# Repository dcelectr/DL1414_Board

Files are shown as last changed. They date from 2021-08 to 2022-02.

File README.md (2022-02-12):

# DL1414_Board
Board design files for Litronix / Siemens / HP DL1414 16-Segment LED displays.
Each board can be stacked with another board and increase the number on total digits.

Arduino test code (scrolling text) for one module is in the [DL1414_74HC595](https://github.com/dcelectr/DL1414_Board/blob/main/DL1414_74HC595/DL1414_74HC595.ino) folder.

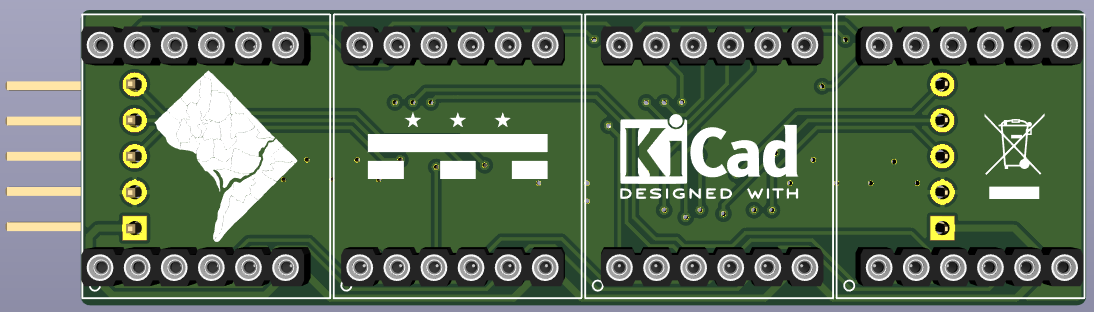
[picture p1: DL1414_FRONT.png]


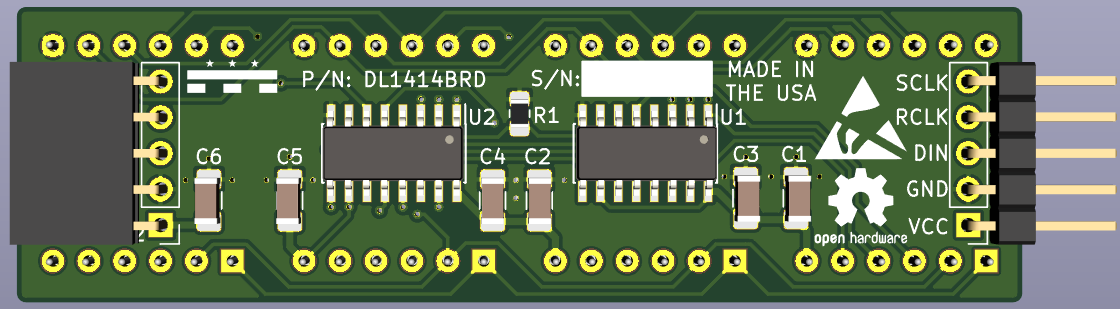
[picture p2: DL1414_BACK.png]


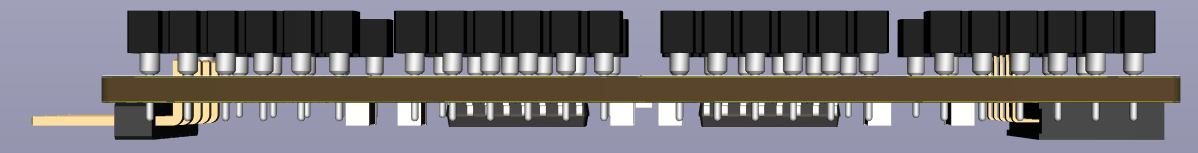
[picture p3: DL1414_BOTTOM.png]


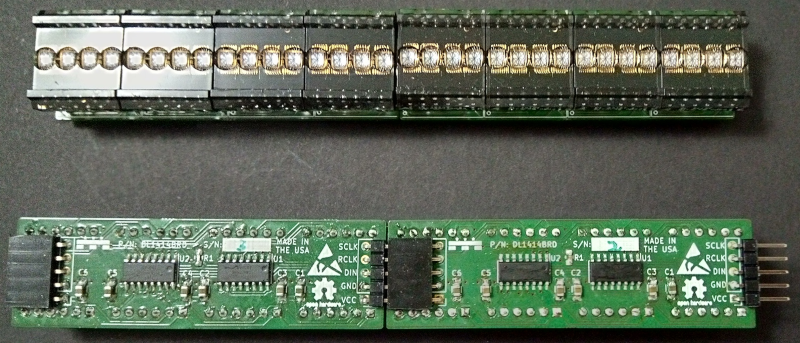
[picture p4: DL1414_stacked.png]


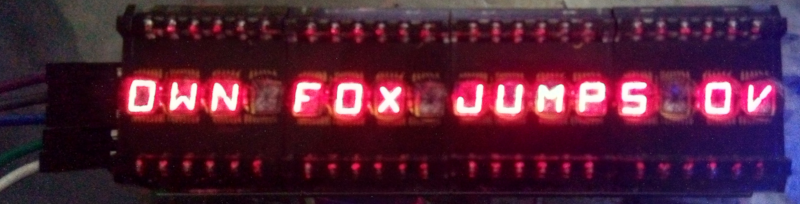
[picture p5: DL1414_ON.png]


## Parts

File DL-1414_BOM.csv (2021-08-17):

Reference | Quantity | Value | Footprint | Datasheet | PN
C1 C2 C3 C4 C5 C6 | 6 | 10uF | Capacitor_SMD:C_1206_3216Metric_Pad1.42x1.75mm_HandSolder | ~ | C1206C106K4PACTU
J1 J2 | 2 | Conn_01x05_Male | Connector_PinHeader_2.54mm:PinHeader_1x05_P2.54mm_Vertical | ~ | PRPC005SBAN-M71RC
R1 | 1 | 0R | Resistor_SMD:R_0805_2012Metric_Pad1.15x1.40mm_HandSolder | ~ | ERJ-6GEY0R00V
U1 U2 | 2 | 74HCT595 | Package_SO:SOIC-16_3.9x9.9mm_P1.27mm | https://assets.nexperia.com/documents/data-sheet/74HC_HCT595.pdf | 74HCT595D-Q100,118
U3 U4 U5 U6 | 4 | DL1414 | User_PCB_Libraries:DL1414 |  | 310-87-106-41-001101 (QTY 2)

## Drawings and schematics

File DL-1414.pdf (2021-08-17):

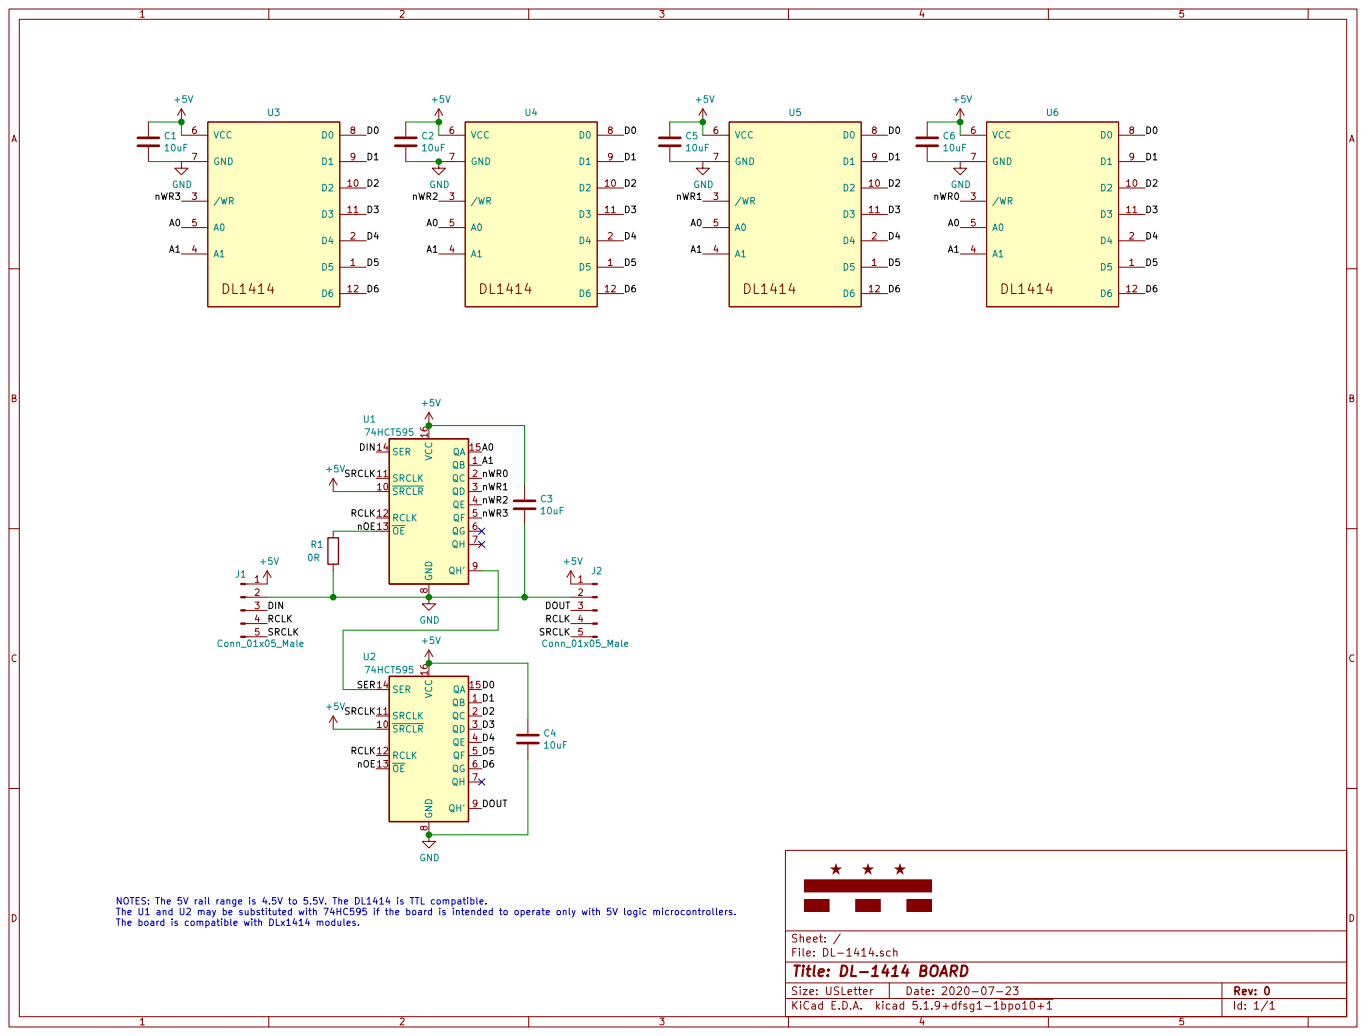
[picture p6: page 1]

The U1 and U2 may be substituted with 74HC595 if the board is intended to operate only with 5V logic microcontrollers.
The board is compatible with DLx1414 modules.

File: DL-1414.sch Sheet: /
Id: 1/1 Title: DL-1414 BOARD

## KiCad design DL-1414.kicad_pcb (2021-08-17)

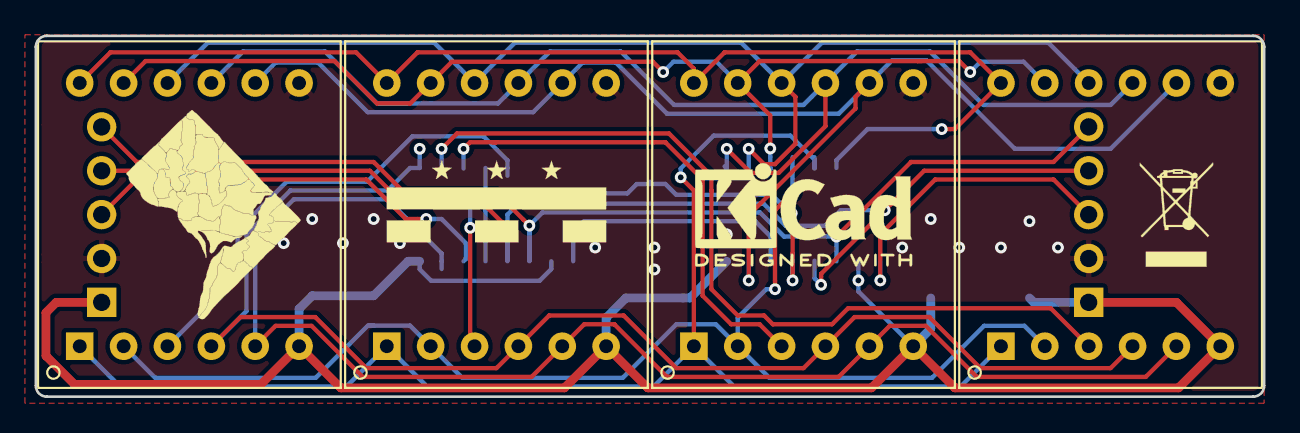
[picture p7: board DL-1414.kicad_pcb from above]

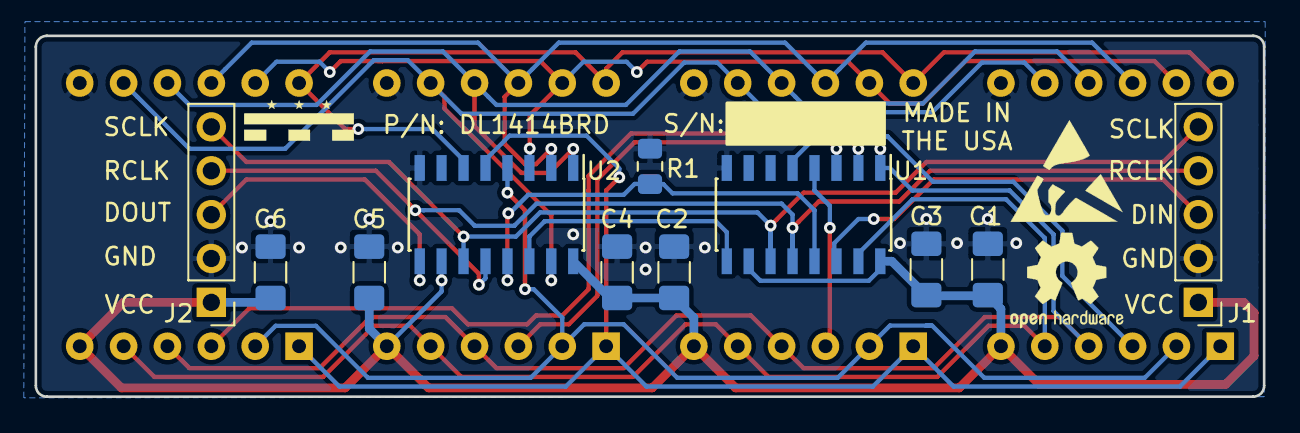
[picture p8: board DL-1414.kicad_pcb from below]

Board: 2 copper layers, 71.1 x 20.9 mm, 15 parts (11 on the bottom side), 21 nets.

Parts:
C1, C2, C3, C4, C5, C6: C; C_1206_3216Metric_Pad1.42x1.75mm_HandSolder
J1, J2: Conn_01x05_Male; PinHeader_1x05_P2.54mm_Vertical
R1: R; R_0805_2012Metric_Pad1.15x1.40mm_HandSolder
U1, U2: 74HC595; SOIC-16_3.9x9.9mm_P1.27mm
U3, U4, U5, U6: DL1414

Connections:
+5V: C1.1, C2.1, C3.1, C4.1, C5.1, C6.1, J1.1, J2.1, U1.10, U1.16, U2.10, U2.16, U3.6, U4.6, U5.6, U6.6
/A0: U1.15, U3.5, U4.5, U5.5, U6.5
/A1: U1.1, U3.4, U4.4, U5.4, U6.4
/D0: U2.15, U3.8, U4.8, U5.8, U6.8
/D1: U2.1, U3.9, U4.9, U5.9, U6.9
/D2: U2.2, U3.10, U4.10, U5.10, U6.10
/D3: U2.3, U3.11, U4.11, U5.11, U6.11
/D4: U2.4, U3.2, U4.2, U5.2, U6.2
/D5: U2.5, U3.1, U4.1, U5.1, U6.1
/D6: U2.6, U3.12, U4.12, U5.12, U6.12
/DIN: J1.3, U1.14
/DOUT: J2.3, U2.9
/RCLK: J1.4, J2.4, U1.12, U2.12
/SER: U1.9, U2.14
/SRCLK: J1.5, J2.5, U1.11, U2.11
/nOE: R1.1, U1.13, U2.13
/nWR0: U1.2, U6.3
/nWR1: U1.3, U5.3
/nWR2: U1.4, U4.3
/nWR3: U1.5, U3.3
GND: C1.2, C2.2, C3.2, C4.2, C5.2, C6.2, J1.2, J2.2, R1.2, U1.8, U2.8, U3.7, U4.7, U5.7, U6.7

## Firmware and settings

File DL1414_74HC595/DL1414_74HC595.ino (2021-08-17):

//**********************************************************************************
//    *   *   *                                                                    *
//  -------------                                                                  *
//  ---  ---  ---                                                                  *
// d c e l e c t r  Library for Litronix / Siemens DL1414 16-Segment LED Displays. *
//**********************************************************************************

#include <SPI.h>

const uint8_t RCLK_PIN = 10; //RCLK, for 74HC595N Storage Register Clock
const uint8_t SDA_PIN  = 11; //MOSI, for 74HC595N Serial Data Input
const uint8_t SCLK_PIN = 13; //SCLK, for 74HC595N Shift Register Clock

uint8_t SELECTED_DISP_NUM=0;

//The storage register transfers data to the output buffer when shift register clear (SRCLR) is high. 
//When SRCLR is low, the input shift register is cleared. The SRCLR is connected to Vcc permanently.
//When output enable (OE) is held high, all data in the output buffers is held low and all drain outputs are off. OE is connected to GND permanently.

void setup() {
  SPI.begin();                       //Start the SPI library
  SPI.setBitOrder(MSBFIRST);         //Set the bit order as MSB.
  //SPI.beginTransaction(SPISettings(4000000, MSBFIRST, SPI_MODE0)); // Uncomment this if there is a need to set SPI speed to 4MHz explicitly.  
  pinMode(RCLK_PIN, OUTPUT);        //Data transfers through the storage register on the rising edge of the register clock (RCK).
  pinMode(SDA_PIN, OUTPUT);
  pinMode(SCLK_PIN, OUTPUT);        //The device transfers data out the serial output (SER OUT) port on the rising edge of SRCK.
  digitalWrite(RCLK_PIN, HIGH);
}

void loop() {
  clearDisplay();
  delay(500);
  String messageString = "The quick brown fox jumps over the lazy dog";
  messageString.toUpperCase();
  writeDisplay(messageString);
}

void writeChar(uint8_t DATA, uint8_t ADDR, uint8_t DISP_NUM){

  uint8_t WR_ADDR = ~(ADDR & 0X03); // Address is swapped because D3 D2 D1 D0 is the order of digits and set all WR bits to 1 when inverting the mask
  SPI.transfer(DATA);
  SPI.transfer(WR_ADDR); 
  digitalWrite(RCLK_PIN, HIGH);
  digitalWrite(RCLK_PIN, LOW);

  WR_ADDR = WR_ADDR ^ (0X04<<DISP_NUM);  // flip WR bit to 0
  SPI.transfer(DATA);  
  SPI.transfer(WR_ADDR); 
  digitalWrite(RCLK_PIN, HIGH);
  digitalWrite(RCLK_PIN, LOW);

  WR_ADDR = WR_ADDR ^ (0X04<<DISP_NUM);  // flip WR bit to 1
  SPI.transfer(DATA);  
  SPI.transfer(WR_ADDR); 
  digitalWrite(RCLK_PIN, HIGH);
  digitalWrite(RCLK_PIN, LOW);
}

void clearDisplay(){
  uint8_t CLR_DATA=32;
  for (uint8_t i=0; i<4; i++){
    uint8_t CLR_ADDR = i;
    writeChar(CLR_DATA, CLR_ADDR, SELECTED_DISP_NUM);
  } 
}

void writeDisplay(String message){

  char displaybuffer[4] = {' ', ' ', ' ', ' '};
 
  for (uint8_t i=0; i<(message.length())+4; i++) {
    // scroll down display
    displaybuffer[0] = displaybuffer[1];
    displaybuffer[1] = displaybuffer[2];
    displaybuffer[2] = displaybuffer[3]; 
    if (i<(message.length())){
      displaybuffer[3] = message[i];
      }
    else{
      displaybuffer[3] = {' '}; 
      } 
    // send a message!
    for (uint8_t j=0; j<4; j++) {
    writeChar(displaybuffer[j],j,SELECTED_DISP_NUM);
    }
    delay(300);
  }
}

void charTest(){
  // Function for testing only (loop)
  writeChar('A',0,SELECTED_DISP_NUM);
  writeChar('B',1,SELECTED_DISP_NUM);
  writeChar('C',2,SELECTED_DISP_NUM);
  writeChar('D',3,SELECTED_DISP_NUM);
  delay(1000);
  for (uint8_t ii=32; ii < 93; ++ii){
    for (uint8_t i=0; i < 4; ++i){
      writeChar({ii+i},i,SELECTED_DISP_NUM);          
    }
    delay(500);   
  }
}
